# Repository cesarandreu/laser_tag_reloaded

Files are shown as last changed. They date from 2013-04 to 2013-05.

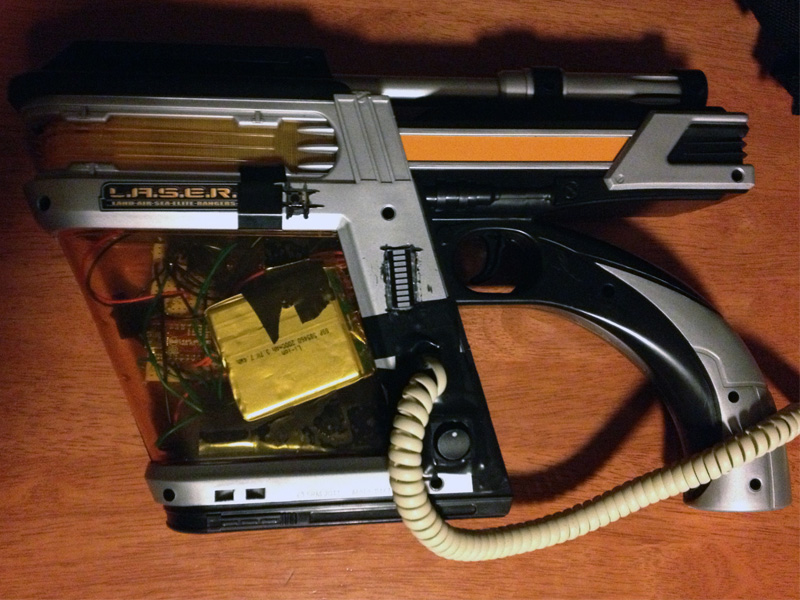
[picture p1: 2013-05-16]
Other/Gun_Image.jpg

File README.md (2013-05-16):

#Laser Tag Reloaded - System

---

##What is this

This is a laser tag system which connects to your android smartphone using bluetooth. Your smartphone then connects to a remote server which handles tracking the lobby and game data. 

The program flow is simple: You pair the smartphone with the gun/vest, you join or create a lobby, and then you play! 

Each player is assigned a number, which gets transmitted by the infrared laser. When another player receives a valid enemy number it transmits this to the smartphone, and then the smartphone transmits it to the server.

When the end game conditions are met, the server nofies every player. At the end of each game you can see a map with markers showing the places where you got shot. 

---

###Project Links

The project has three components: 

* [__System__ (Gun + Vest)](https://github.com/cesarandreu/laser_tag_reloaded)

* [__Server__ (Node.js) ](https://github.com/cesarandreu/laser_tag_nodejs)

* [ __Smartphone application__ (Android)](https://github.com/cesarandreu/laser_tag_android)

Videos

* [System demonstration](http://www.youtube.com/watch?v=hs2FppfotFk)

---

###System

The system (gun + vest) has an infrared laser, two infrared receivers, a speaker, a bluetooth module, a GPS module, a battery gauge, a battery charger, a battery, an LED bar graph, and two push-buttons. 

The essential components are: the infrared laser, the infrared receivers, the speaker, the bluetooth, and the push-button. (And a power source.) These components are required for the system to function. You could remove the LED graph, second button, battery charger, battery gauge, and GPS, and still maintain system functionality. (Although this would require commenting out the appropriate code in _real-main.c_ and _game.c_ in order to prevent any issues.)

Everything is controlled through bluetooth commands. The system changes through different states depending on which command is sent. You can see the bluetooth commands in the _communication.c_ library; you can also see the game code for each command in the _game.c_ library. 

Basically, the system goes into a _Connected_ state when bluetooth communication is established. Then it goes to _New Game_ mode, which initializes all the interrupts, the storage, and the player variables. Afterwards it awaits for the _Game Information_ command which tells it the game type, the game limit, the list of enemy numbers, and your own player number. When it receives the _Game Start_ command it enables the receivers and trigger button. From this point on the game is live, and whenever a shot is received it transmits the number and location data to the smartphone; when the trigger is pressed the infrared laser transmits your player code. When the server decides that the game has ended it informs the smartphone, the smartphone then sends a _Game End_ command, which resets all the variables, sends everything that is in storage, and disables the receivers and trigger. 

At this point you could start a new game from the smartphone, and the whole process would be repeated.

---

####Picture of the system

Picture of Gun

This is a picture of the final gun. We purchased this toy gun and modded it to put the board and all the components inside. It connects to a vest through a phone cable. 

---

####Building your own

If you wish to build your own you can find the schematic inside the _Other_ folder. You can also find a list of all the components in our report.

Once you've put the system together you'll have to configure the [command-line toolchain](http://leaflabs.com/docs/unix-toolchain.html). It's only tested on the [maple mini](http://leaflabs.com/docs/hardware/maple-mini.html), but it should work on the maple if you update _initialize.c_ accordingly. 

After that you should be able to clone this repository and run `make`, and then `make install`. 

__WARNING:__ You can take a look at the `Tests` folder for some of the tests we used, or to get an idea of how some of the code works. However, we haven't updated all the files inside, so some may be outdated. Use them at your own risk.

---

####More Information

Inside the _Other_ folder you can find the report that we prepared for our professor. In there you can find information on the components, power analysis, timing analysis, and an in-depth description of the whole system. Pretty much all the information is there. We've included the schematics as well.

There's also a folder with a PCB that we designed. However, we were unable to print and test it. If you decide to print the PCB you'll have to wirewrap two sections in order to ensure uniform ground. We recommend wire-wrapping the ground plane that contains the SDA and SCL pins of the battery monitor to the ground plane containing the Trigger button, and from there, wire-wrap to any other ground-plane in order to ensure uniform ground potential.

If you have any questions feel free to contact us, or just raise an issue. We'll be glad to help if we can.

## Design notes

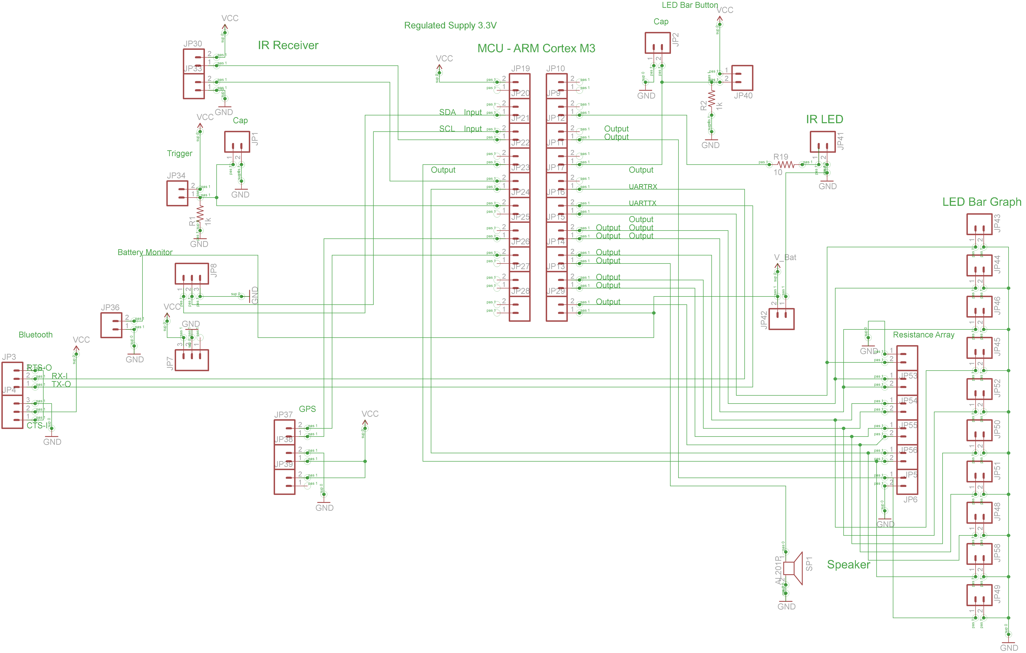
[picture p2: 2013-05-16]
Other/Schematic/Laser Tag Reloaded schematic.png

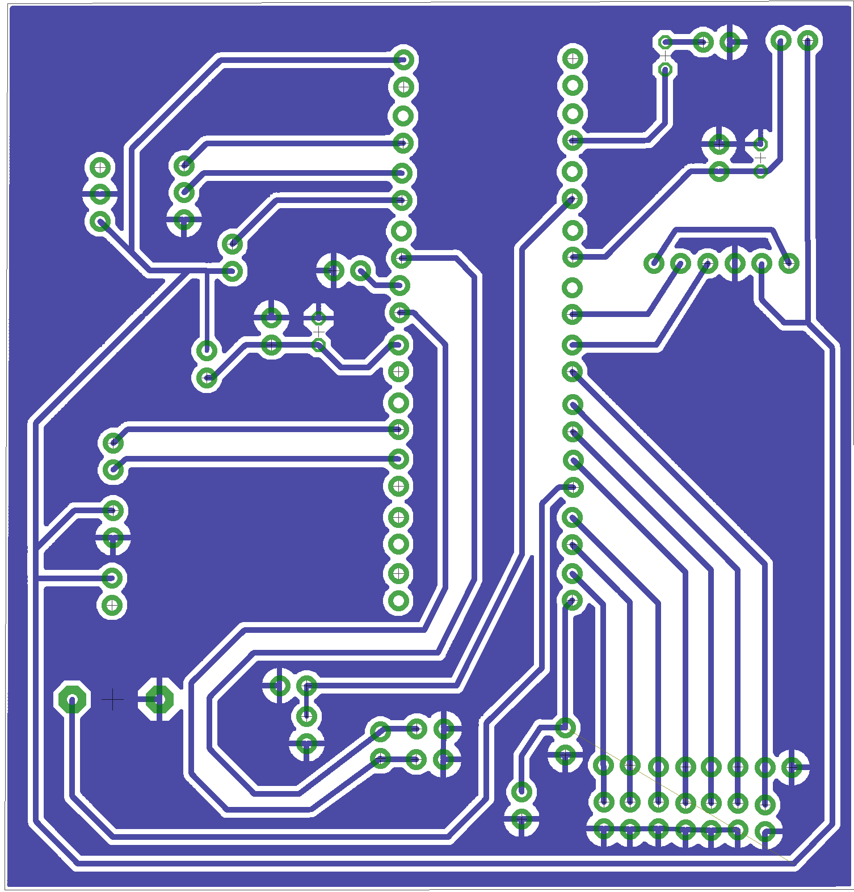
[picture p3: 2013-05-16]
Other/PCB/Laser Tag Reloaded PCB.png

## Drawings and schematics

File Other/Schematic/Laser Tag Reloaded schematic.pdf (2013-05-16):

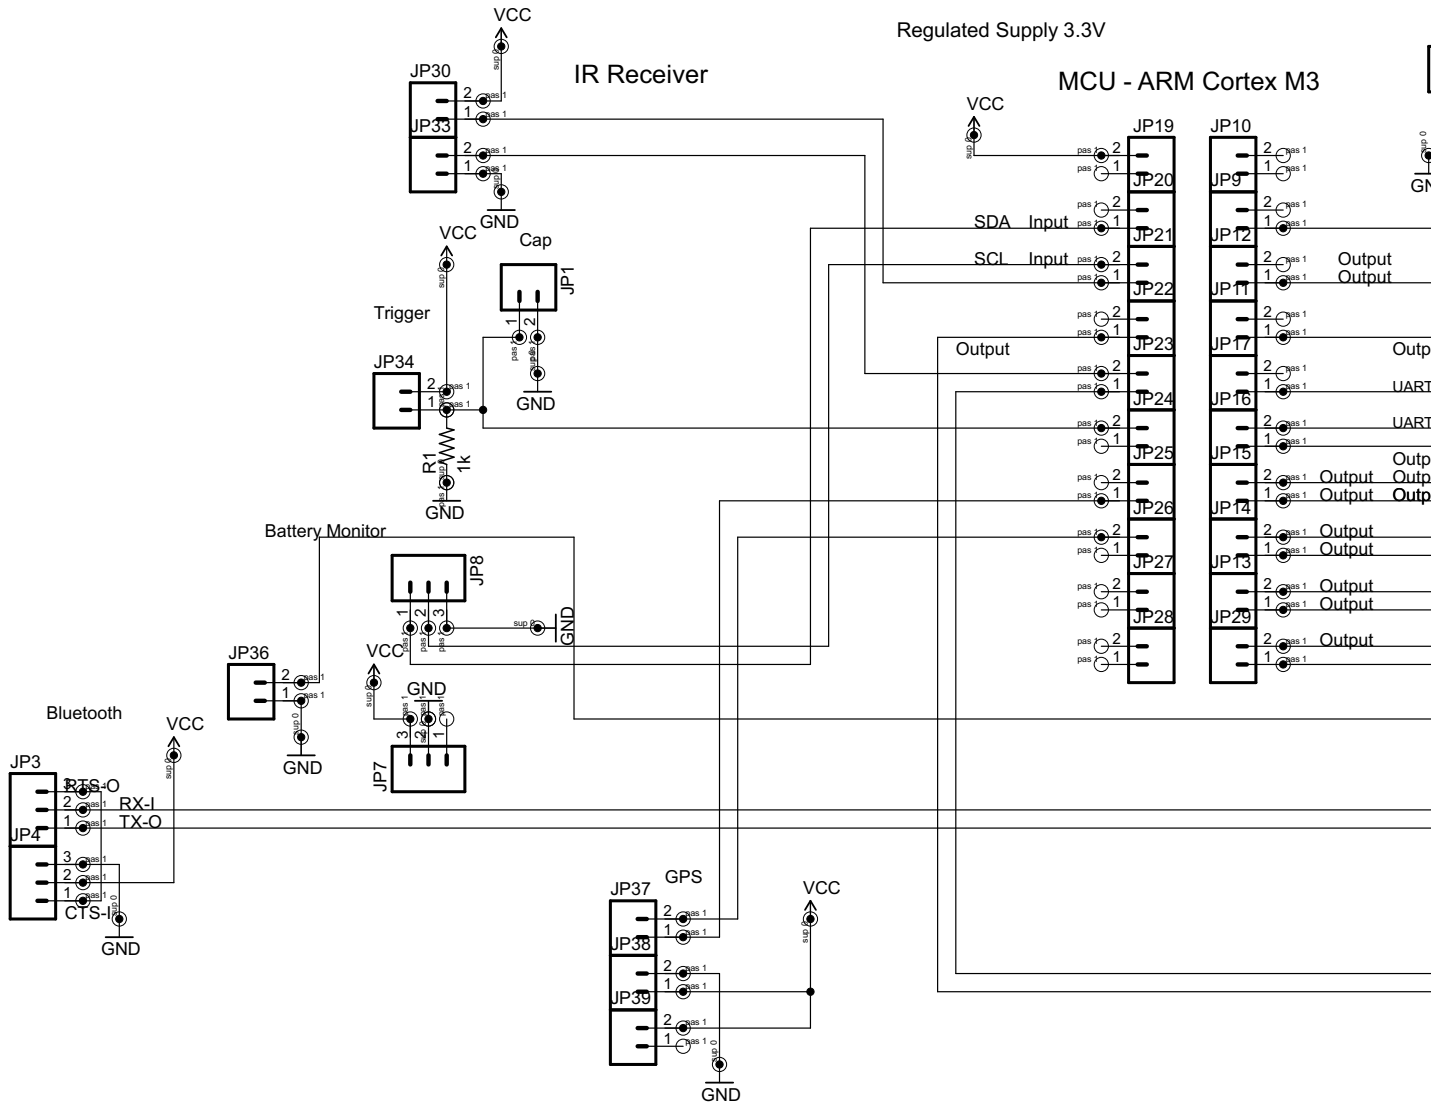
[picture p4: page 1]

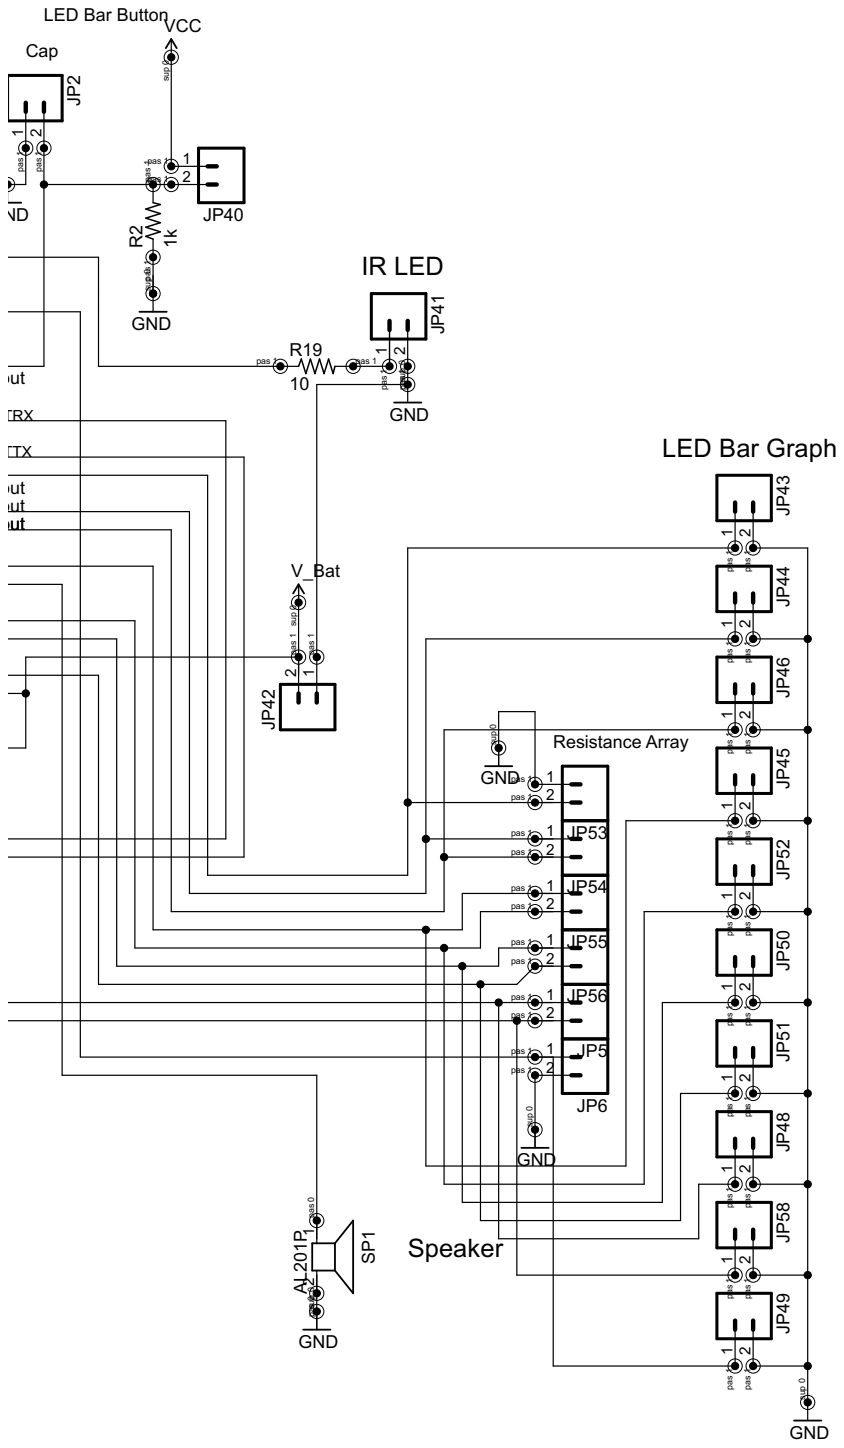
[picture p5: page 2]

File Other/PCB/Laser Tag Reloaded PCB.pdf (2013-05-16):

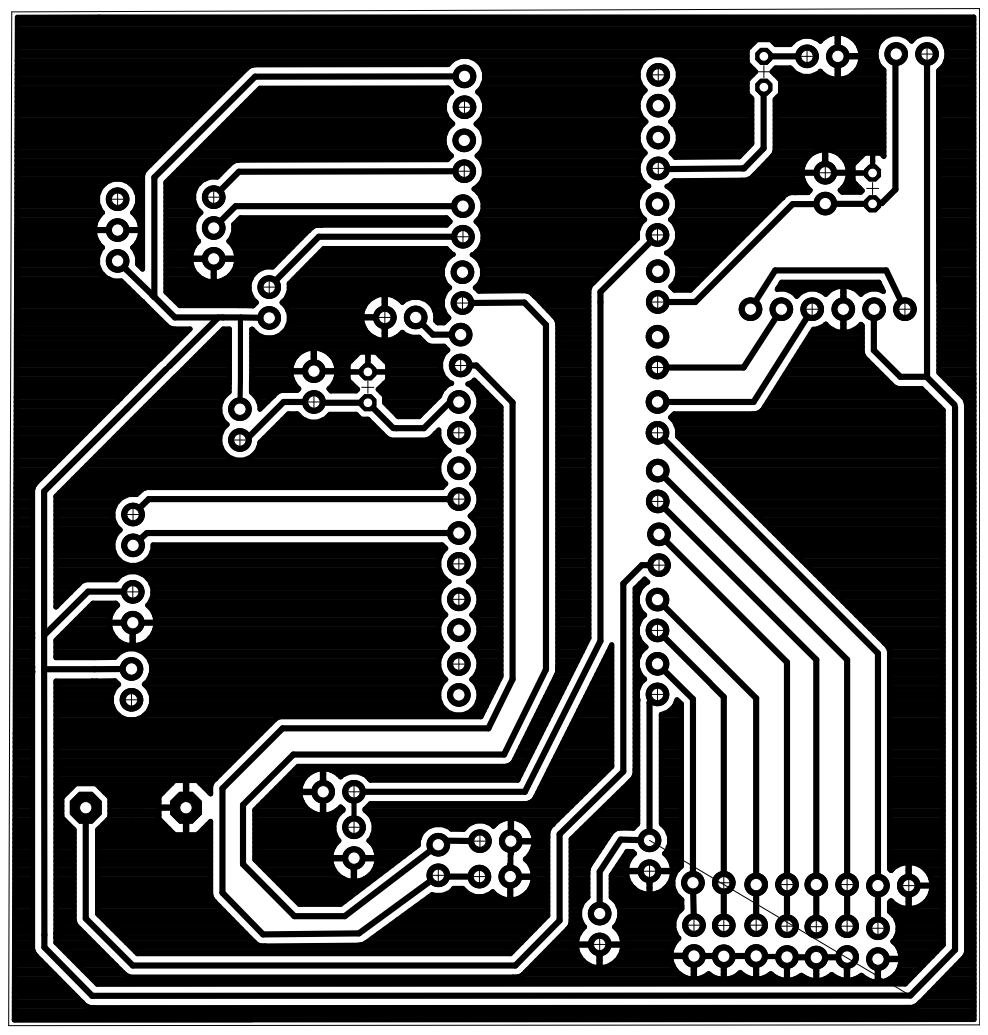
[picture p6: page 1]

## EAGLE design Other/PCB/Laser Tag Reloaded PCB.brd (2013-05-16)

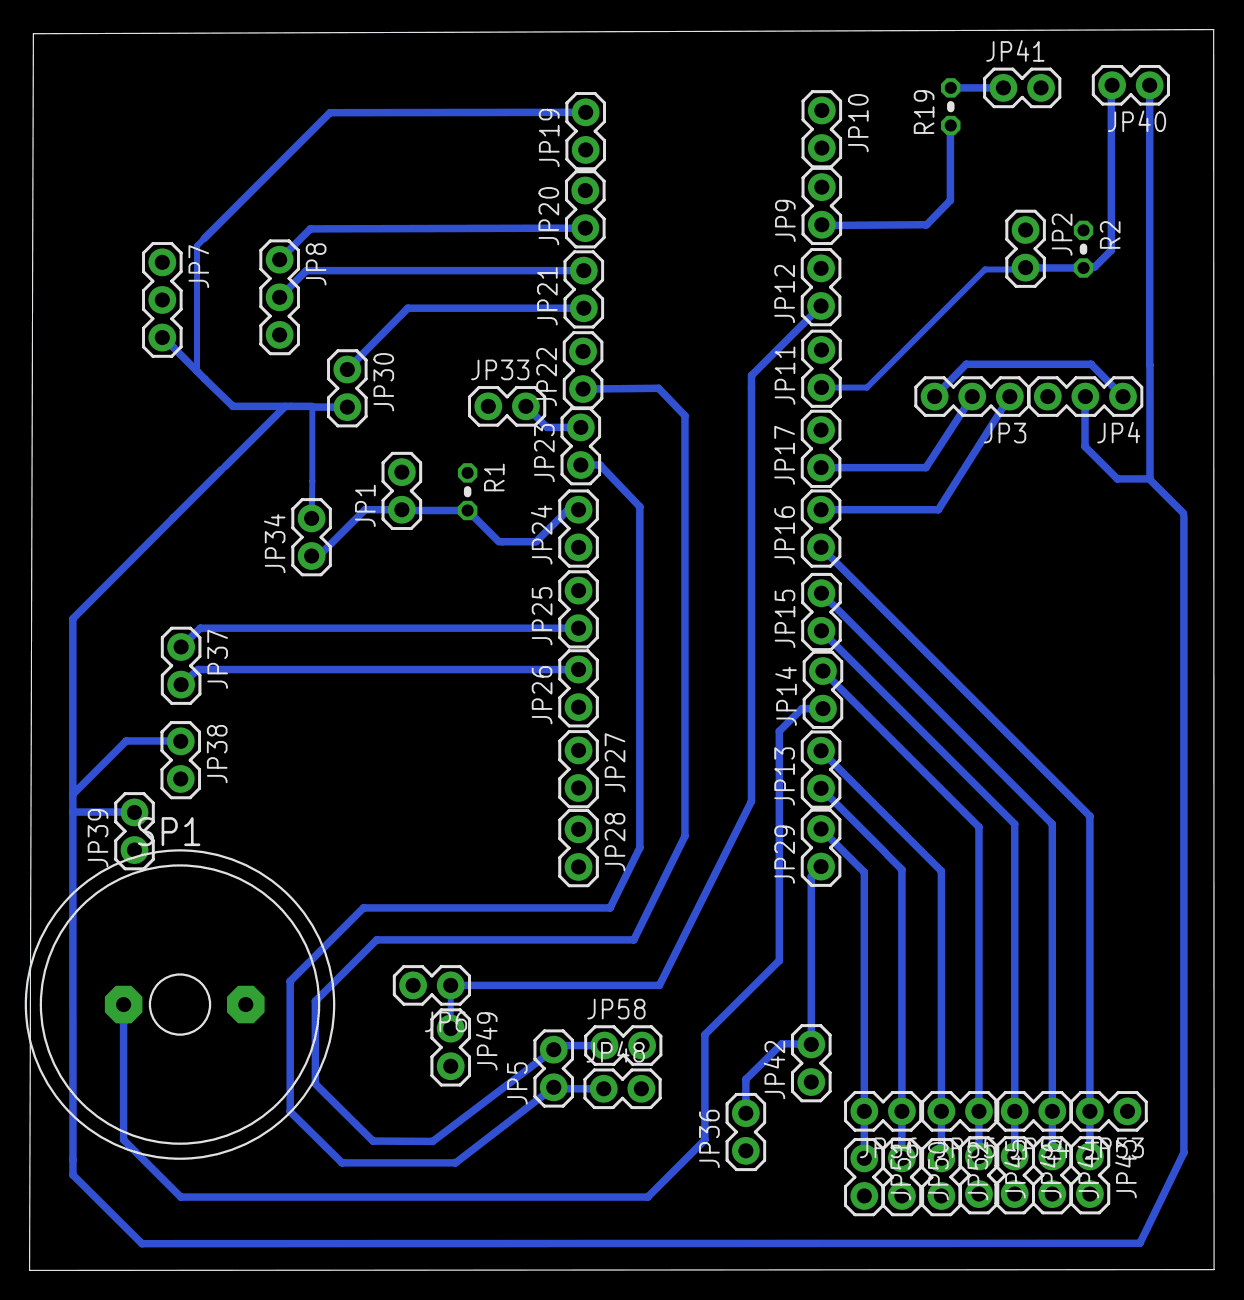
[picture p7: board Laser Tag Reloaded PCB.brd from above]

Board: 2 copper layers, 80.0 x 83.8 mm, 56 parts (0 on the bottom side), 26 nets.

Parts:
JP1, JP2, JP5, JP6, JP9, JP10, JP11, JP12, JP13, JP14, JP15, JP16, JP17, JP19, JP20, JP21, JP22, JP23, JP24, JP25, JP26, JP27, JP28, JP29, JP30, JP33, JP34, JP36, JP37, JP38, JP39, JP40, JP41, JP42, JP43, JP44, JP45, JP46, JP48, JP49, JP50, JP51, JP52, JP53, JP54, JP55, JP56, JP58: 1X02
JP3, JP4, JP7, JP8: 1X03
R1, R2: 1k; 0204V
R19: 10; 0204V
SP1: AL201P

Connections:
GND: JP1.2, JP2.1, JP4.3, JP6.2, JP7.2, JP8.3, JP33.1, JP36.1, JP38.2, JP41.2, JP42.1, JP43.2, JP44.2, JP45.2, JP46.2, JP48.2, JP49.2, JP50.2, JP51.2, JP52.2, JP53.1, JP58.2, R1.1, R2.1, SP1.2
unnamed: JP1.1, JP24.2, JP34.1, R1.2
unnamed: JP3.3, JP4.1
unnamed: JP5.2, JP22.1, JP58.1
unnamed: JP21.1, JP30.1
unnamed: JP23.2, JP33.2
unnamed: JP41.1, R19.2
unnamed: JP2.2, JP11.1, JP40.2, R2.2
unnamed: JP5.1, JP23.1, JP48.1
unnamed: JP25.1, JP37.1
unnamed: JP26.2, JP37.2
unnamed: JP8.1, JP20.1
unnamed: JP9.1, R19.1
unnamed: JP8.2, JP21.2
unnamed: JP6.1, JP12.1, JP49.1
unnamed: JP14.1, SP1.1
unnamed: JP3.2, JP17.1
unnamed: JP3.1, JP16.2
unnamed: JP16.1, JP43.1, JP53.2
unnamed: JP15.2, JP44.1, JP54.1
unnamed: JP15.1, JP46.1, JP54.2
unnamed: JP14.2, JP45.1, JP55.1
unnamed: JP13.2, JP52.1, JP55.2
unnamed: JP13.1, JP50.1, JP56.1
unnamed: JP29.2, JP51.1, JP56.2
VCC: JP4.2, JP7.3, JP19.2, JP29.1, JP30.2, JP34.2, JP36.2, JP38.1, JP39.2, JP40.1, JP42.2

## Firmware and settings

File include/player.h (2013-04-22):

#ifndef _PLAYER_H_
#define _PLAYER_H_

/* Conditional extern "C" so we're safe to call from C++ files */
#ifdef __cplusplus
extern "C" {
#endif

#define DEFAULT_PLAYER_CODE 1
#define DEFAULT_SHOTS_FIRED 0

// [ 2 <-> (2^8)-1] are the allowed numbers (between 2 and 255)
#define MAXIMUM_PLAYER_NUMBER 255
#define MINIMUM_PLAYER_NUMBER 2
    
    
void player_start(int);
void player_shoot(void);
int player_getShots(void);
int player_getCode(void);
void player_setCode(int);
void player_reset(void);

#ifdef __cplusplus
}
#endif

#endif 

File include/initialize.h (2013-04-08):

/******************************************************************************
 * The MIT License
 *
 * Copyright (c) 2011 LeafLabs, LLC.
 *
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
 * THE SOFTWARE IS PROVIDED "AS IS", WITHOUT WARRANTY OF ANY KIND,
 * EXPRESS OR IMPLIED, INCLUDING BUT NOT LIMITED TO THE WARRANTIES OF
 * MERCHANTABILITY, FITNESS FOR A PARTICULAR PURPOSE AND
 * NONINFRINGEMENT. IN NO EVENT SHALL THE AUTHORS OR COPYRIGHT HOLDERS
 * BE LIABLE FOR ANY CLAIM, DAMAGES OR OTHER LIABILITY, WHETHER IN AN
 * ACTION OF CONTRACT, TORT OR OTHERWISE, ARISING FROM, OUT OF OR IN
 * CONNECTION WITH THE SOFTWARE OR THE USE OR OTHER DEALINGS IN THE
 * SOFTWARE.
 *****************************************************************************/

//@TODO: Organize this file more. Remove redundant or useless data.

#ifndef _INITIALIZE_H_
#define _INITIALIZE_H_

/* Conditional extern "C" so we're safe to call from C++ files */
#ifdef __cplusplus
extern "C" {
#endif


#include <libmaple/libmaple_types.h>
#include <libmaple/gpio.h>
#include <libmaple/timer.h>
#include <libmaple/flash.h>
#include <libmaple/nvic.h>
#include <libmaple/systick.h>
#include <libmaple/rcc.h>

void init(void);


#define CYCLES_PER_MICROSECOND    72
#define SYSTICK_RELOAD_VAL     71999 /* takes a cycle to reload */

#define BOARD_BUTTON_PIN          32
#define BOARD_LED_PIN             33

#define BOARD_NR_USARTS           3
#define BOARD_USART1_TX_PIN       26
#define BOARD_USART1_RX_PIN       25
#define BOARD_USART2_TX_PIN       9
#define BOARD_USART2_RX_PIN       8
#define BOARD_USART3_TX_PIN       1
#define BOARD_USART3_RX_PIN       0

#define BOARD_NR_SPI              2
#define BOARD_SPI1_NSS_PIN        7
#define BOARD_SPI1_MOSI_PIN       4
#define BOARD_SPI1_MISO_PIN       5
#define BOARD_SPI1_SCK_PIN        6
#define BOARD_SPI2_NSS_PIN        31
#define BOARD_SPI2_MOSI_PIN       28
#define BOARD_SPI2_MISO_PIN       29
#define BOARD_SPI2_SCK_PIN        30

#define BOARD_NR_GPIO_PINS        34
#define BOARD_NR_PWM_PINS         12
#define BOARD_NR_ADC_PINS          9
#define BOARD_NR_USED_PINS         4

#define BOARD_JTMS_SWDIO_PIN      22
#define BOARD_JTCK_SWCLK_PIN      21
#define BOARD_JTDI_PIN            20
#define BOARD_JTDO_PIN            19
#define BOARD_NJTRST_PIN          18

#define BOARD_USB_DISC_DEV        GPIOB
#define BOARD_USB_DISC_BIT        9



/*
 * Derived and default board definitions
 */

#define CLOCK_SPEED_MHZ                 CYCLES_PER_MICROSECOND
#define CLOCK_SPEED_HZ                  (CLOCK_SPEED_MHZ * 1000000UL)

#ifndef SYSTICK_RELOAD_VAL
#define SYSTICK_RELOAD_VAL              (1000 * CYCLES_PER_MICROSECOND - 1)
#endif

#ifndef BOARD_BUTTON_PRESSED_LEVEL
#define BOARD_BUTTON_PRESSED_LEVEL      HIGH
#endif

/**
 * @brief Does the board break out a USART/UART's RX and TX pins?
 *
 * BOARD_HAVE_USART(n) is nonzero iff USARTn is available (n must be
 * an integer literal, 1 through 6). Also see BOARD_HAVE_USART1, ...,
 * BOARD_HAVE_UART4 (sic), etc.
 */
#define BOARD_HAVE_USART(n) (defined(BOARD_USART##n##_TX_PIN) && \
                             defined(BOARD_USART##n##_RX_PIN))
/** Feature test: nonzero iff the board has USART1. */
#define BOARD_HAVE_USART1               BOARD_HAVE_USART(1)
/** Feature test: nonzero iff the board has USART2, 0 otherwise. */
#define BOARD_HAVE_USART2               BOARD_HAVE_USART(2)
/** Feature test: nonzero iff the board has USART3, 0 otherwise. */
#define BOARD_HAVE_USART3               BOARD_HAVE_USART(3)
/** Feature test: nonzero iff the board has UART4, 0 otherwise. */
#define BOARD_HAVE_UART4                BOARD_HAVE_USART(4)
/** Feature test: nonzero iff the board has UART5, 0 otherwise. */
#define BOARD_HAVE_UART5                BOARD_HAVE_USART(5)
/** Feature test: nonzero iff the board has USART6, 0 otherwise. */
#define BOARD_HAVE_USART6               BOARD_HAVE_USART(6)

/**
 * @brief Does the board break out a SPI peripheral's pins?
 *
 * BOARD_HAVE_SPI(n) is nonzero iff SPIn is available (n must be an
 * integer literal: 1, 2, or 3). Also see BOARD_HAVE_SPI1,
 * BOARD_HAVE_SPI2, BOARD_HAVE_SPI3. */
#define BOARD_HAVE_SPI(n) (defined(BOARD_SPI##n##_NSS_PIN)  &&          \
                           defined(BOARD_SPI##n##_SCK_PIN)  &&          \
                           defined(BOARD_SPI##n##_MISO_PIN) &&          \
                           defined(BOARD_SPI##n##_MOSI_PIN))
/** Feature test: nonzero iff the board has SPI1. */
#define BOARD_HAVE_SPI1 BOARD_HAVE_SPI(1)
/** Feature test: nonzero iff the board has SPI2. */
#define BOARD_HAVE_SPI2 BOARD_HAVE_SPI(2)
/** Feature test: nonzero iff the board has SPI3. */
#define BOARD_HAVE_SPI3 BOARD_HAVE_SPI(3)

/**
 * @brief Feature test: nonzero iff the board has SerialUSB.
 */
#define BOARD_HAVE_SERIALUSB (defined(BOARD_USB_DISC_DEV) && \
                              defined(BOARD_USB_DISC_BIT))


#ifdef __cplusplus
}
#endif

#endif 

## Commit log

2013-04-08 Fixed bluetooth library. Added bluetooth and usb tests.
    [bluetooth_Test.c]
2013-04-08 Updated bluetooth with some printing functions.
2013-04-09 Adding GPS header, C implementation, and test code. Also adding i2c headers and implementations.
2013-04-15 Update receiver.c
    added a return to listenForIR that if currentPulse >5 return 0
2013-04-16 Working on fixing the receiver. When you press the pushbutton it'll trigger the receiver interrupt.
2013-04-18 Updated bluetooth so that all the defines are in the header. Updates player so that the shots fired cannot pass one million. Added communication library which can properly parse received information!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
2013-04-20 Fixed communication.c, it was printing the game type without quotation marks. Added communicationResponseTransmit_Test. It works with all the commands from what I can tell.
    [communicationResponseTransmit_Test.c]
2013-04-20 IT COMPILES. Yay! Added game library. It handles the game logic. Well, it handles the state changes in the system. Added function calls to game library from communication. Modified receiver library s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
    On a personal note: I feel like a badass right now. I feel like today I've made a lot of progress! :D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
2013-04-22 Moved some of the game related logic to game.c, it was originally in communication.c. Now the enemies are put in an array and then they're added to the enemy library from game.c. Added some defines t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
    communication.c specific:
    Updated one of the responses so that now it sends the player number.
    Added some safety escape condition to getNext.
    Added a bit of documentation on top of each different type of parsing function.
    Added some minimum/maximum length exit conditions to these parsing functions.
    Created a resetBuffer f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
    [player.h]
2013-04-22 Made the player library use signed integers for the shot counter. Increased the maximum number of hits to 128 in the storage library. Made game over response respond with the response number. Fixed a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
    [player.h]
2013-04-22 Added timer to GPS implementation to wait for fix.
    GPS coordinate string size corrected.
    Added USART buffer clearing in relevant functions.
    Also added a small comment in receiver.c and removed some old test code.
2013-04-23 Fixed gps_hasFix blocking and some other minor hiccups.
    Added trigger.h and trigger.c to handle trigger enable/disable and
    interrupt enabling/disabling.
2013-04-26 Mother forgive me.
    Basically bailed on low-power on GPS for the time being, it will go
    into low-power tracking though.
    Fixed gauge_voltage in gauge implementation.
    Added some minor test code to receiver to confirm interrupt operation.
    Back receiver code has been (sloppily) implemented, need to fix some
    variable names.
    LEDGraph has been added, needs some cleaning.
    Some shoddy tests have been implemented as real-main variations, I will
    be adapting them to the tests folder later.
2013-05-01 Small changes to storage and game to make it slightly more robust in case of magical failure.
2013-05-10 Currently working! Moved includes from game.c to game.h Increased storage size from 128 to 256 Made it so that storage_add returns the hit it added Renamed trigger function names Set some communicati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
2013-05-10 Fixed trigger interrupt.
2013-05-10 Added LED Graph code. When you press the button it gets the battery percentage.
2013-05-16 Added schematic, updating README.
2013-05-16 Added schematics, PCB, report and image. Updated README.
    [Laser Tag Reloaded PCB.brd, Laser Tag Reloaded schematic.sch]

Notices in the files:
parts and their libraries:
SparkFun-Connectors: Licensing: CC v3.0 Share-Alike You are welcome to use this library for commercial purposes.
